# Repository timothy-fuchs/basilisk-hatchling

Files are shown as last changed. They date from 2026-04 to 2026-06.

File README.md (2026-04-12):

# basilisk-hatchling.github.io
Hatching a basilisk inside a Raspberry Pi Zero 2 W - based Macintosh

## License

Unless otherwise noted, the original content in this repository is licensed
under the Creative Commons Attribution-ShareAlike 4.0 International License
(CC BY-SA 4.0). See [LICENSE](./LICENSE) and the site [license page](./license.md).

That license applies only to material contained in this repository. It does not
extend to third-party materials or to any external repository, website, or
other internet resource linked from this project.

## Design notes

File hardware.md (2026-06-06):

---
layout: page
title: Hardware
permalink: /hardware/
---

# Things you absolutely need to obtain

Use this as a shopping checklist while gathering parts.

## 1. Maclock

Best sourced on AliExpress. Look for a listing with decent reviews. YMMV.

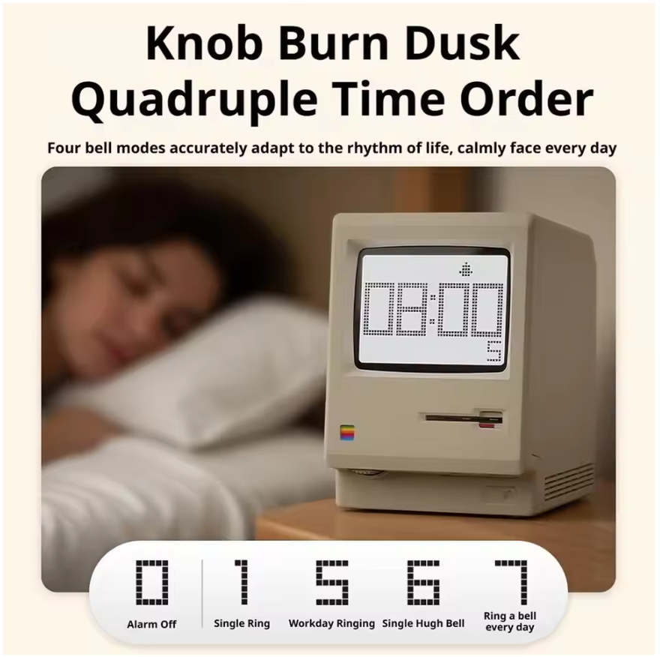
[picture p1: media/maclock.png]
Creative translation is an added bonus


## 2. Raspberry Pi Zero 2 W

Best sourced with the header already soldered on. If you can find a kit that includes a radiator, get it.

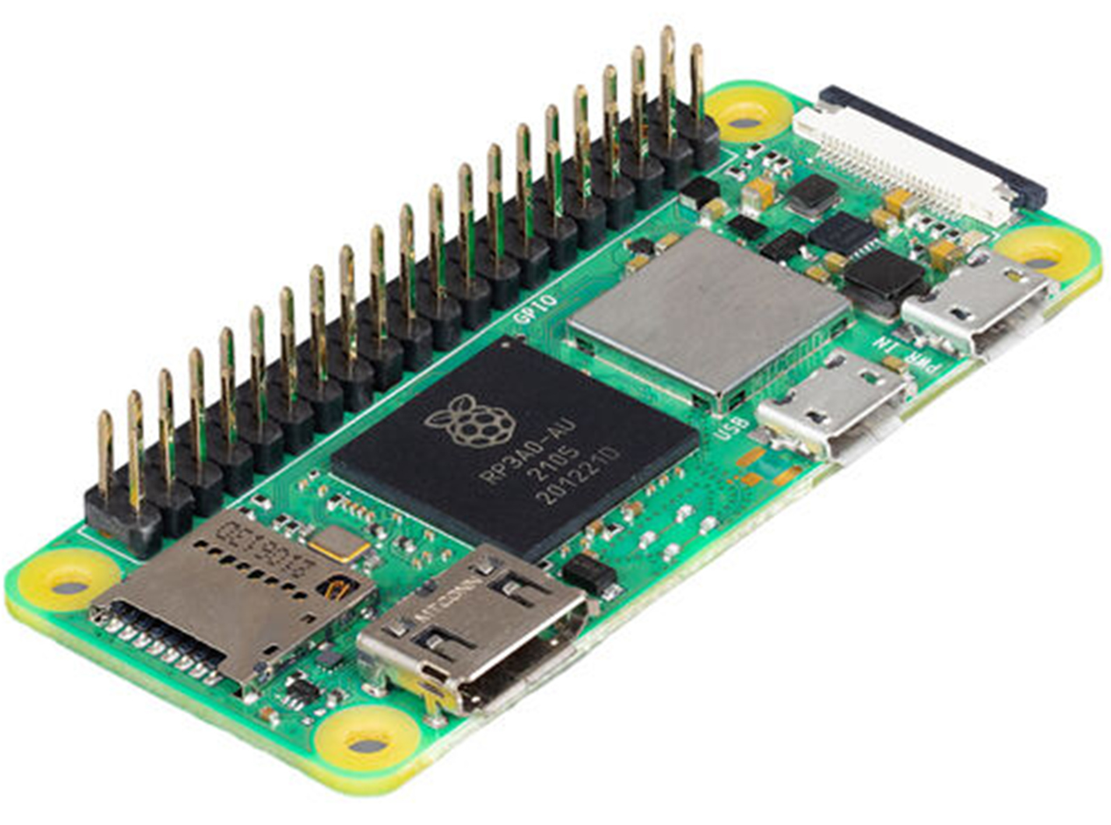
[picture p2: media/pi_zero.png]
Raspberry Pi


## 3. Waveshare 2.8" LCD display

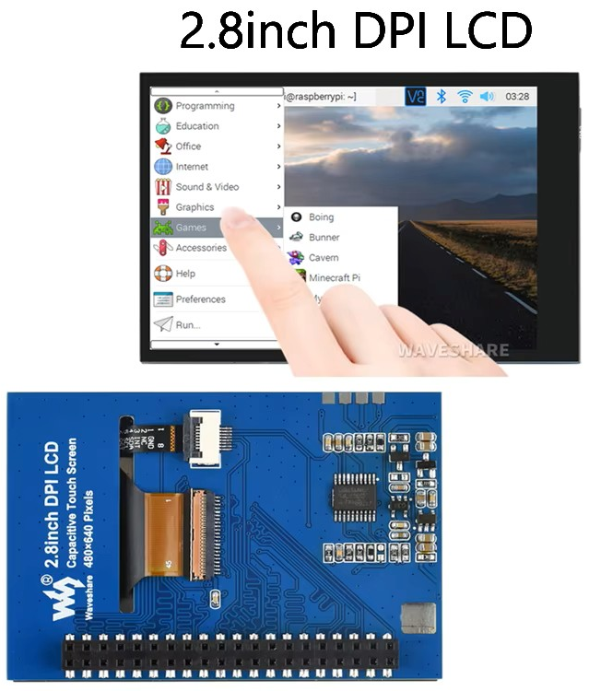
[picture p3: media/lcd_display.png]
LCD Display


## 4. Raspberry Pi 12mm header extender

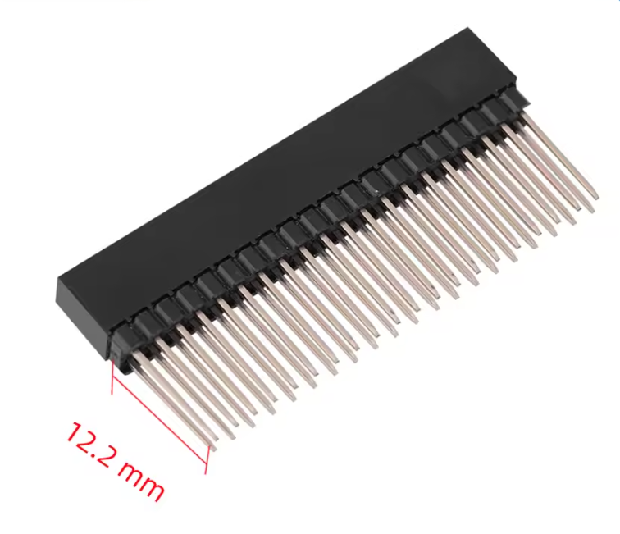
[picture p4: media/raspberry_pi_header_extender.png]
extender


## 5. Two angled microUSB-to-USB-C panel-mount adapters

Best sourced on AliExpress. Search term: `angled 90 microUSB to USB-C panel mount adapter`.

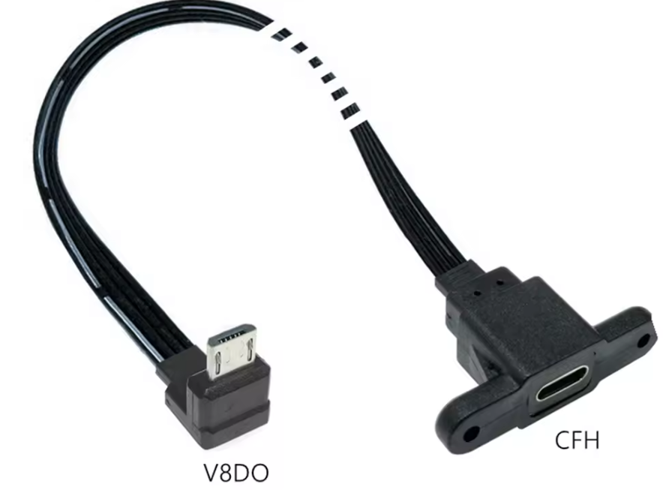
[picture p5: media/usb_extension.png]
Angled MicroUSB to USB-C panel mount


## 6. MicroSD extender

Best sourced on AliExpress. Search term: `microSD extension cable` or `sd card extension cable`.

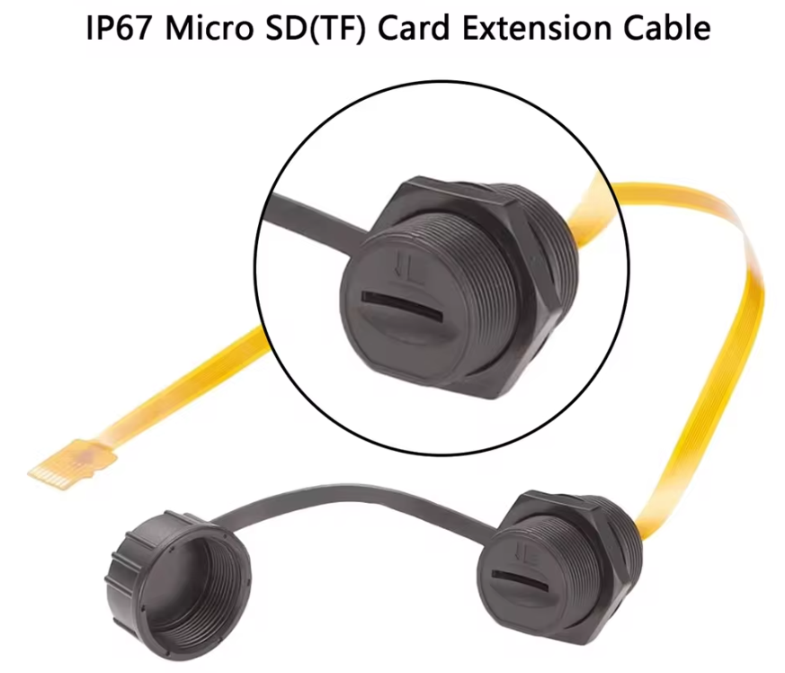
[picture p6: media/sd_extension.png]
MicroSD extender


## 7. USB-C to USB hub

Best sourced on AliExpress.

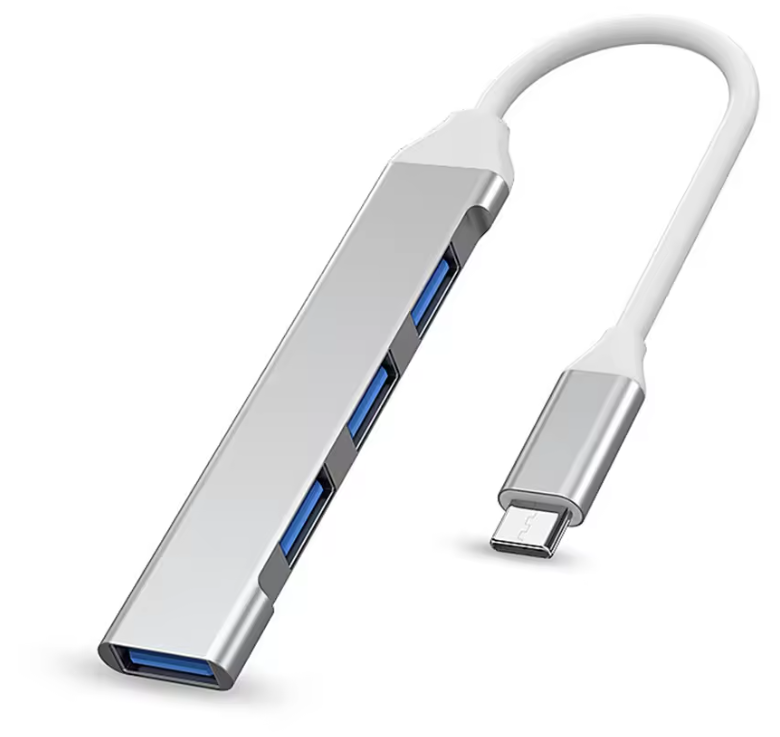
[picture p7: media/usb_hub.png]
USB


## 8. PWM sound HAT (optional)

This is supposed to work, but I have not tried it. Search for `dtoverlay=audremap,pins_18_19` if you want to test this option.

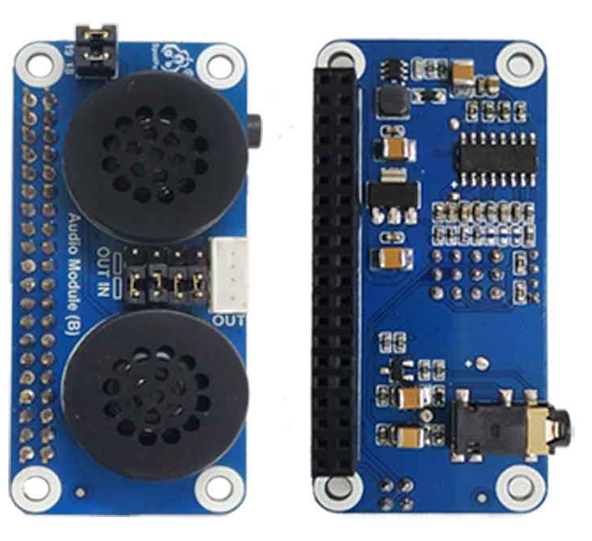
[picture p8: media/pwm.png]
PWM


## 9. USB audio dongle (optional)

Best sourced on AliExpress.

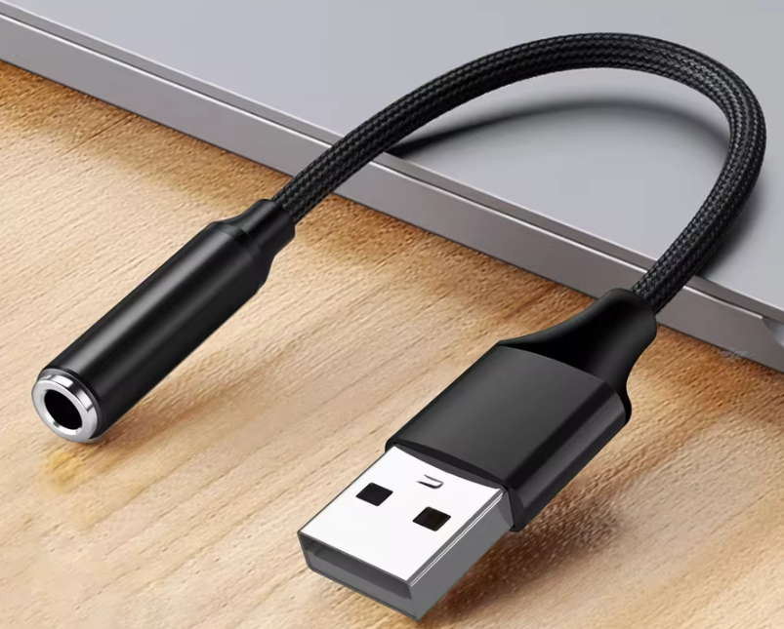
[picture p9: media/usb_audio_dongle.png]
USB Audio


## 10. Power supply

Best sourced on AliExpress. Search term: `USB-C power supply`.
I've been using this one, it works fine, but it is obviously not the only option. Raspberry Pi Zero 2 W has very modest power requirements.
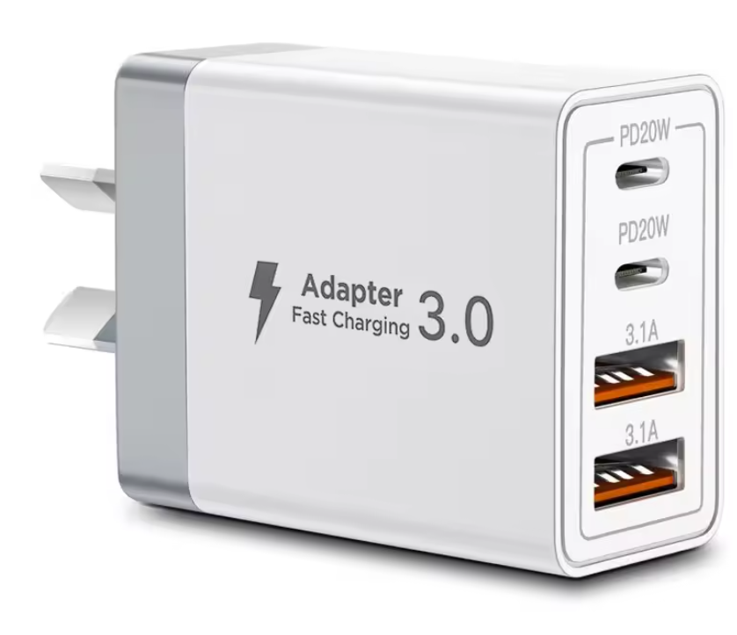
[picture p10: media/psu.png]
Power supply


# Things that you will need to 3D print

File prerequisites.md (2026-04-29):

---
layout: page
title: Prerequisites
permalink: /prerequisites/
---

# OS
Since we are going to use the SDL2 library, the X11 framework is a hindrance, so we will not install it at all.  
Use Raspberry Pi Imager to flash **Raspberry Pi OS Lite (32-bit)**.  
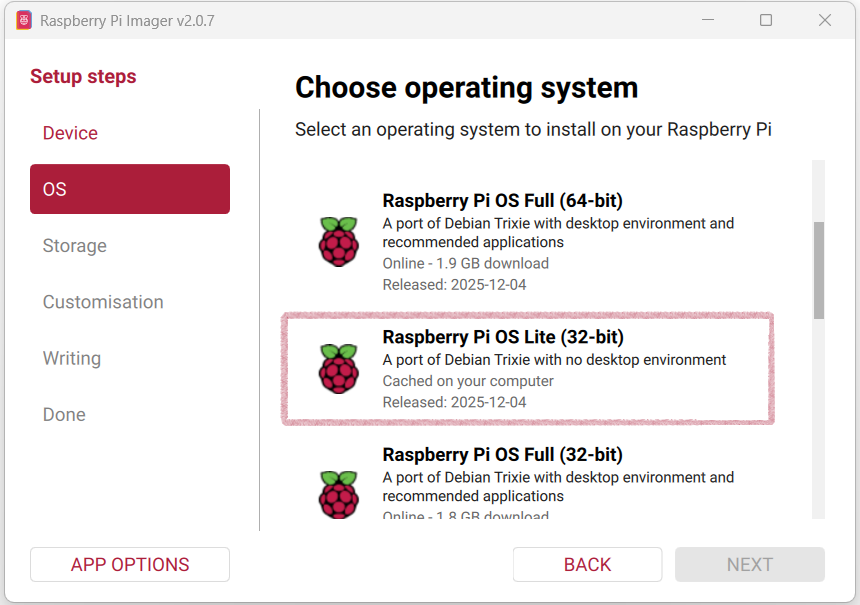
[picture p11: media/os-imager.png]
Raspberry Pi OS Lite - 32-bit


**Note:** Further instructions assume that we chose the default account name.

Flash the image onto the MicroSD card.

# Waveshare LCD drivers
*Note: Waveshare Wiki — [2.8inch DPI LCD](https://www.waveshare.com/wiki/2.8inch_DPI_LCD?spm=a2g0n.appdesc.0.0.130eA0ssA0ssp1&file=2.8inch_DPI_LCD)*  
Please read it before proceeding, since the process of deploying their driver may change.

Open the `config.txt` file in the root directory of the TF card, add the following lines at the end, and save:

```
dtoverlay=vc4-kms-v3d
dtoverlay=waveshare-28dpi-3b-4b   
dtoverlay=waveshare-28dpi-3b
dtoverlay=waveshare-28dpi-4b
dtoverlay=waveshare-touch-28dpi
dtoverlay=vc4-kms-dpi-2inch8
```

Download the DTBO file from  
https://files.waveshare.com/wiki/2.8inc-DPI-LCD/28DPI-DTBO.zip,  
unzip it, and copy the contents into `/boot/overlays`.

*At this stage, we should be ready to insert the TF card with the OS image into your Raspberry Pi and boot into the OS.*

```
sudo raspi-config
```
Enable SSH access.

# Console orientation
The first thing we will notice at boot time is that the console appears sideways.  
Build and install Basilisk, and its UI will appear sideways too (don’t ask me how I know).  
A `video` kernel command-line argument will not fix the problem for Basilisk, but we can at least correct the console at this stage.

Open the command-line arguments file for editing:

```sudo vi /boot/firmware/cmdline.txt```
and add the following in front of other arguments:
```video=DPI-1:480x640M@60,rotate=270 ```
Be sure to separate it from other arguments with a space and keep everything on the same line, or it won’t work.

# Build prerequisites
Before doing anything else, bring the OS up to date:

```
sudo apt update
sudo apt full-upgrade -y
sudo reboot
```

Since we will build the SDL2 library and Basilisk II emulator from source, we need to install the build tools and essential libraries:

```
sudo apt install -y \
    build-essential \
    git \
    autoconf \
    automake \
    libtool \
    pkg-config \
    libsdl2-dev \
    libasound2-dev \
    libslirp-dev \
    libgtk-3-dev \
    libgl1-mesa-dev \
    libgles2-mesa-dev
```

# Downloading, configuring, and building SDL2
*Note: Check the [download page](https://libsdl.org/release/) and get the latest SDL2 release. Do not download SDL3 (don’t ask me how I know).*

At the time of writing, **SDL2-2.32.10** was the latest release. Adjust accordingly.
```
mkdir projects
cd ~/projects
wget https://libsdl.org/release/SDL2-2.32.10.tar.gz
tar xf SDL2-2.32.10.tar.gz
cd SDL2-2.32.10
```

Configure SDL2 without X11, Wayland, PulseAudio, or OpenGL, and with KMSDRM
```
./configure \
    --disable-video-x11 \
    --disable-video-wayland \
    --disable-video-opengl \
    --disable-video-vulkan \
    --disable-pulseaudio \
    --disable-esd \
    --enable-video-kmsdrm \
    --enable-video-rpi \
    --enable-video-dummy
```

Build and install
```
make -j4
sudo make install
sudo ldconfig
```

This gives you a pure KMSDRM SDL2 build, ideal for headless Basilisk II.

# Downloading, configuring, and building Basilisk II
*Note: popular kanjitalk755 fork does not play nice with Waveshare LCD panels. This fork does.*
```
cd ~/projects
git clone https://github.com/timothy-fuchs/macemu.git
cd macemu/BasiliskII/src/Unix
```
Configure and build
`./autogen.sh`

Configure Basilisk II for:
* SDL2 video/audio
* No X11
* No GTK
* No JIT (safer on ARM)
* No VOSF

 ```
./configure --enable-sdl-video --enable-sdl-audio --disable-vosf --disable-jit --without-x --without-gtk --disable-nls --disable-esd --disable-mon
```
Build and deploy
```
make -j4
sudo make install
```

Before we go any further, let's install file hfs system utitlites that will make our life considerably more tolerable in the near future:
`sudo apt install hfsutils`

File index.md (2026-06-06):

---
layout: home
title: Home
---
This project is a miniature replica of the classic Macintosh, running Basilisk II on a Raspberry Pi Zero 2 W, and using a Waveshare 2.8" LCD display as the screen.

# Sinister but cute. Cute but sinister.
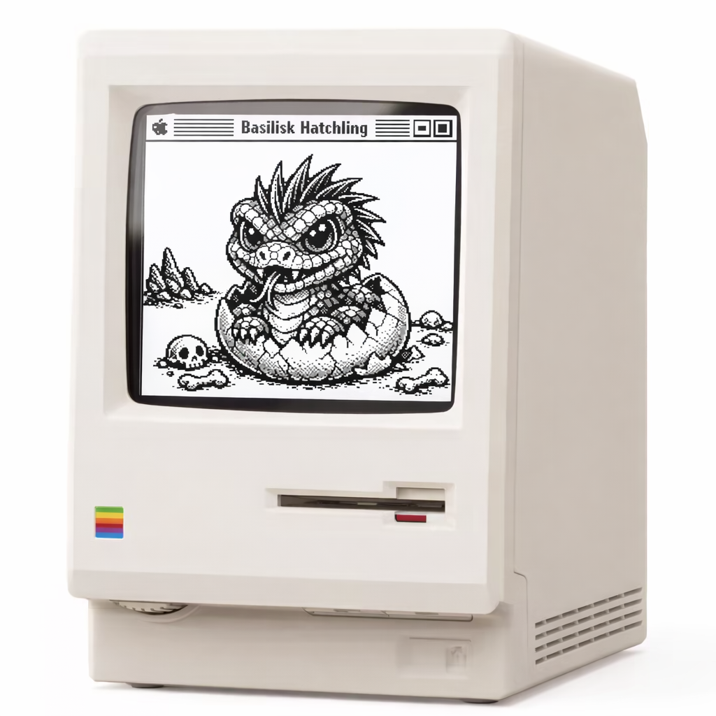
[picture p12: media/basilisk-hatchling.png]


The inspiration for this project came from this video by @ThisDoesNotCompute:

<div style="position: relative; padding-bottom: 56.25%; height: 0; overflow: hidden;">
    <iframe
        src="https://www.youtube.com/embed/dRr5iVjMfqs"
        style="position: absolute; top: 0; left: 0; width: 100%; height: 100%;"
        frameborder="0"
        allowfullscreen>
    </iframe>
</div>

He has done an amazing job finding the right parts and putting everything together, however, I felt that his choice of the OS and emulator was not optimal, and I decided to do it my own way, documennting my journey along the way.

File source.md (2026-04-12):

# Basilisk Hatchling
[media/basilisk__hatchling.png]

## Parts
* Raspberry Pi Zero W 2
* Waveshare 2.8" LCD monitor
* 
Lorem ipsum

## Installation process
* Correct at the time of writing *
* OS - raspbian Trixie Lite (headless)
** install with the default settings.
** Configure WiFi.
** Enable ssh.

** Configure the LCD
*Note: Waveshare Wiki is here: https://www.waveshare.com/wiki/2.8inch_DPI_LCD?spm=a2g0n.appdesc.0.0.130eA0ssA0ssp1&file=2.8inch_DPI_LCD*
*** Open the config.txt file in the root directory of the TF card, add the following code at the end of the config.txt and save:
```
dtoverlay=vc4-kms-v3d
dtoverlay=waveshare-28dpi-3b-4b   
dtoverlay=waveshare-28dpi-3b
dtoverlay=waveshare-28dpi-4b
dtoverlay=waveshare-touch-28dpi
dtoverlay=vc4-kms-dpi-2inch8
```
Download the DTBO file https://files.waveshare.com/wiki/2.8inc-DPI-LCD/28DPI-DTBO.zip , unzip and copy into /boot/overlays

** Ssh into the hatchling.

*** Enable VNC.
*** To correct screen orientation, add the following to the beginning of `/boot/firmware/cmdline.txt`, separate by space.
`video=DPI-1:480x640M@60,rotate=270`

*** Update the system
```
sudo apt update
sudo apt full-upgrade -y
sudo reboot
```

*** Install the prerequisites
```
sudo apt install -y \
    build-essential \
    git \
    autoconf \
    automake \
    libtool \
    pkg-config \
    libsdl2-dev \
    libasound2-dev \
    libslirp-dev \
    libgtk-3-dev \
    libgl1-mesa-dev \
    libgles2-mesa-dev
```

*** Download, configure, and build SDL2 (Headless / KMSDRM Only)
*Note: check the download page, download the latest release of SDL2 available. Do not download SDL3*
```
cd ~
wget https://libsdl.org/release/SDL2-2.32.10.tar.gz
tar xf SDL2-2.32.10.tar.gz
cd SDL2-2.32.10
```

** Configure SDL2 without X11, Wayland, PulseAudio, or OpenGL, and with KMSDRM
```
./configure \
    --disable-video-x11 \
    --disable-video-wayland \
    --disable-video-opengl \
    --disable-video-vulkan \
    --disable-pulseaudio \
    --disable-esd \
    --enable-video-kmsdrm \
    --enable-video-rpi \
    --enable-video-dummy
```
*** Build and install
```
make -j4
sudo make install
sudo ldconfig
```
This gives you a pure KMSDRM SDL2, ideal for headless Basilisk II.

** Clone and build Basilisk II
*Note: the credit for porting Basilisk II to SDL2 goes to kanjitalk755, but his implementation does not play nice with waveshare LCD panels. My fork does.*
```
cd ~
git clone https://github.com/timothy-fuchs/macemu.git
cd macemu/BasiliskII/src/Unix
```

*** Configure and build 
`./autogen.sh`

*** Configure Basilisk II for:

**** SDL2 video/audio
**** No X11
**** No GTK
**** No JIT (safer on ARM)
**** No VOSF
 
 ```
./configure     --enable-sdl-video     --enable-sdl-audio     --disable-vosf     --disable-jit     --without-x     --without-gtk     --disable-nls     --disable-esd     --disable-mon
```

Install the hfs utilities
`sudo apt install hfsutils`

Create the main drive image
dd ...
Create the transfer drive image

Create the basilisk configuration.
Mount the boot floppy disk
Boot - at this stage you should get

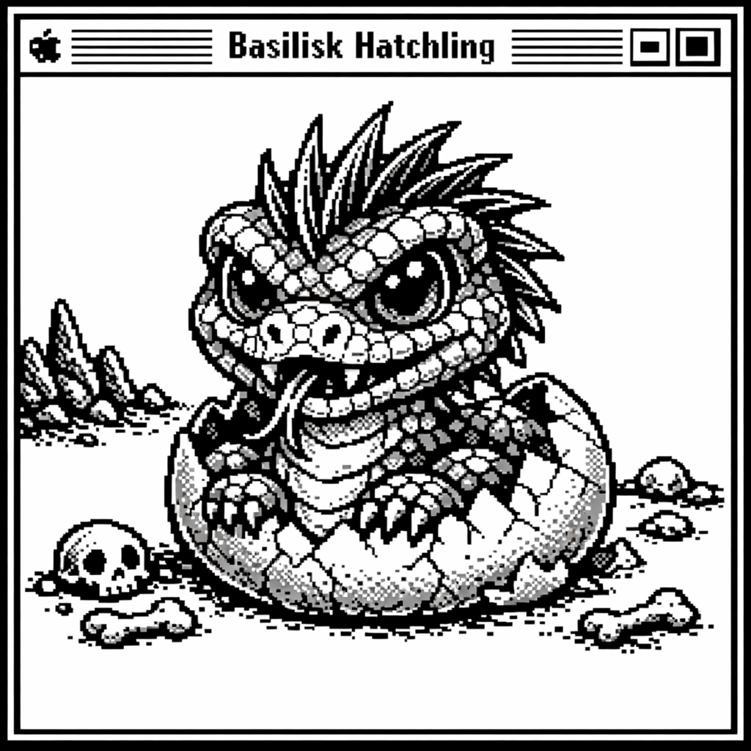
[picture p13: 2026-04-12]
media/basilisk-hatchling-window.png

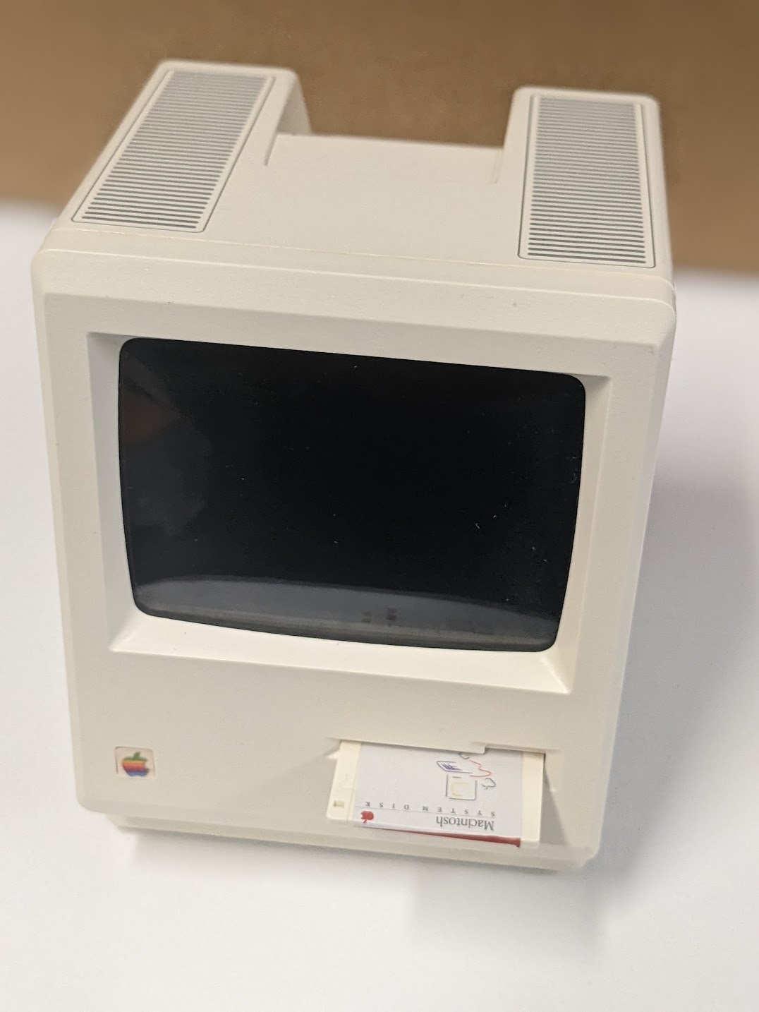
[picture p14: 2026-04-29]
media/mac_front.jpg

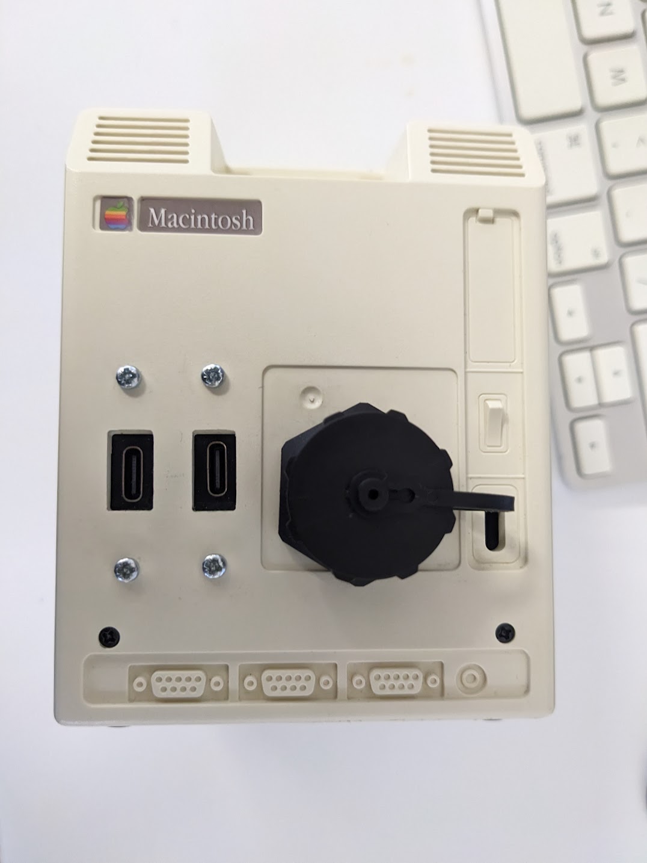
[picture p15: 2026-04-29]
media/mac_back.jpg

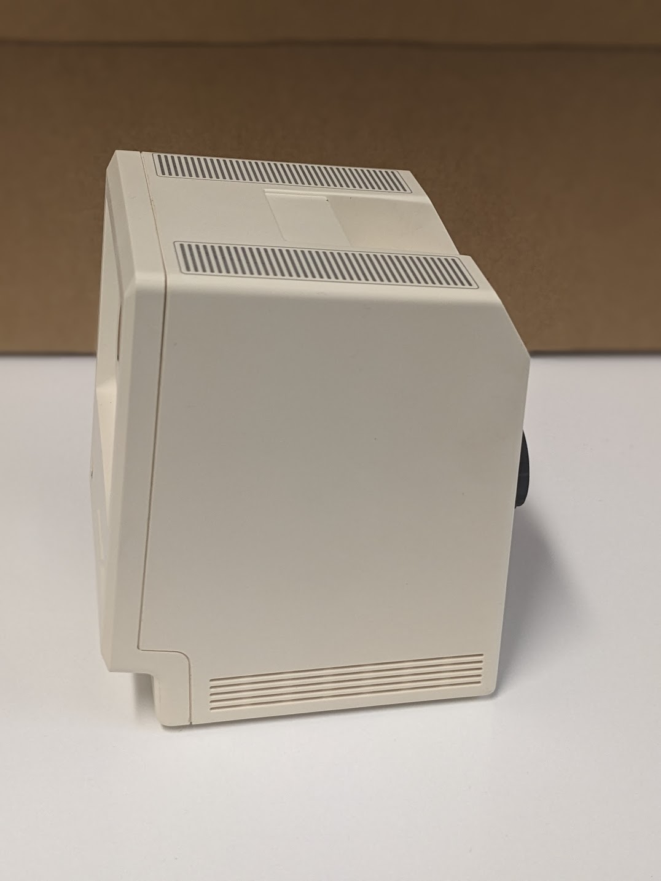
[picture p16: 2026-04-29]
media/mac_side.jpg

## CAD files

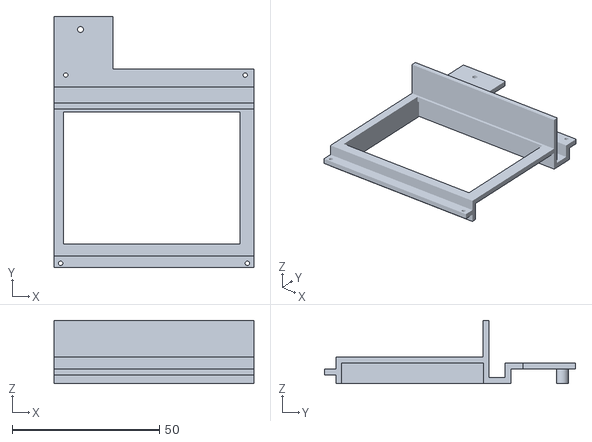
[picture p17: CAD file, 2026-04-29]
media/wondermac-screen-bracket-full-image-remix.stl
68.0 x 85.5 x 21.5

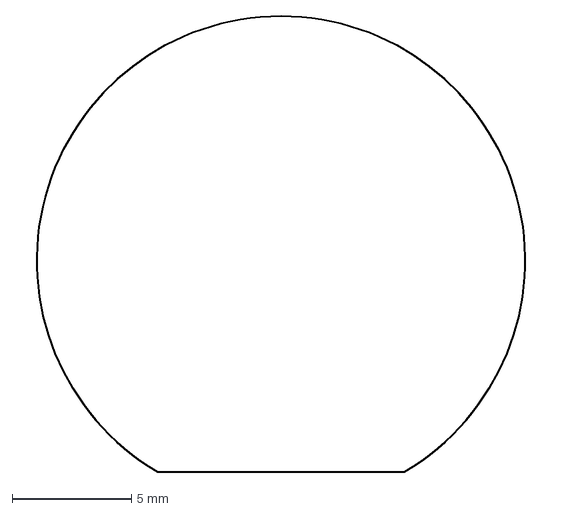
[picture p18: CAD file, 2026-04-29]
media/microsd_reader_aperture.dxf
22.2 x 19.1 mm

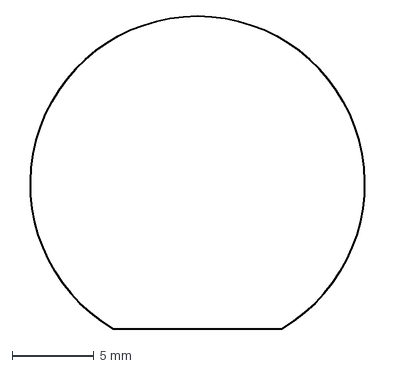
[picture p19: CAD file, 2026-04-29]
media/cf_card_slot.dxf
22.2 x 19.1 mm

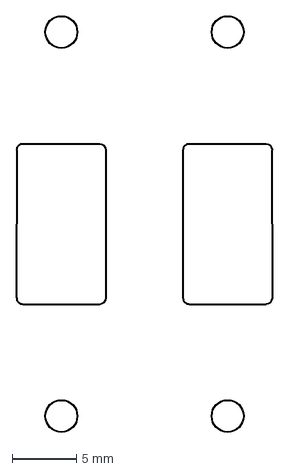
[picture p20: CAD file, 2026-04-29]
media/usb_cutouts.dxf
20.0 x 32.5 mm

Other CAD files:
media/wondermac-screen-bracket-full-image.stl

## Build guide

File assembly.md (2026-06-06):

---
layout: page
title: Assembly
permalink: /assembly/
---
Disassembly of the Maclock is the hardest part of the entire project. Below is a step-by-step guide to disassembling the Maclock and preparing it for the installation of the Raspberry Pi and LCD display. I can only add that the process is quite tedious and that you are guaranteed to break at least one of the plastic clips. Make sure you break the clips at the bottom, because it is invisible and does not affect the aesthetics of the final product. Use a plastic prying tool to avoid damaging the case. Take your time and be patient.

<div style="position: relative; padding-bottom: 56.25%; height: 0; overflow: hidden;">
    <iframe
        src="https://www.youtube.com/embed/WEVMEvV_sOM"
        style="position: absolute; top: 0; left: 0; width: 100%; height: 100%;"
        frameborder="0"
        allowfullscreen>
    </iframe>
</div>

Once you have disassembled the Maclock, you will need to prepare the case for the installation of the Raspberry Pi and LCD display. The original instructable, linked below for your reference, reuses the original charging port by rewiring the charging socket board. I found this to be tedious. The wiring is fragile, and once soldered, the two parts of the maclock case cannot be separated without breaking the wires. Raspberry Pi Zero 2 W has a micro USB port for power, and there is no reason to not make use of it and try to use the probe pads on the Raspberry Pi for power instead. I left the original charging port in place, unconnected and cut two holes in the case back for two USB ports, one for power and one for the USB hub. I chose to use Micro USB to USB-C panel mount adapters for the ports, because they are sturdy and robust unlike the increasingly rare and fragile Micro USB ports.

Additionally, I cut a large hole in the back of the case for the CF card slot, so that I could easily reprogram the Raspberry Pi without having to open the case.

*Power switch*:
Angled MicroUSB to USB-C panel mount
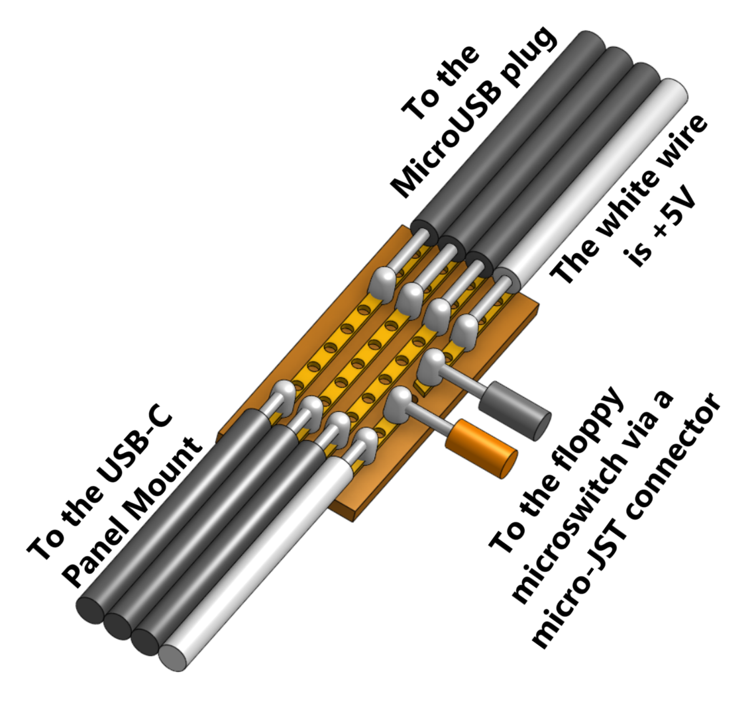
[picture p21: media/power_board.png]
Bypass
    
I  cut one of the Micro USB to USB-C cables in half and inserted a DIY bypass with a switch, using a micro-JST pigtail and a piece of stripboard to allow to turn the power on and off without having to unplug the cable. It allowed me to use the mock floppy drive as a power switch, which is a nice touch, if I do say so myself.

For your build, you can follow the instructable below, with the appropriate adjustments. 
*Nota Bene!:* 

The instructable calls for trimming the borders with a pair of side cutters. I found this to be entirely unnecessary, and I did not do it. The 3D printed LCD display frame fits perfectly in the original opening without any modifications, and the borders are not visible when the case is closed.

[Instructable](https://www.instructables.com/Wireless-Mini-Mac-From-a-Maclock/)

The video below takes this project one siginificant step further than I did by adding a custom PCB for the Raspberry Pi and reusing the the original brigtness control knob and two pushbuttons. It also adds an internal speaker for even greater authenticity. It is an amazing project, and if you feel adventurous, you can try to follow his instructions to add these features to your build as well.

<div style="position: relative; padding-bottom: 56.25%; height: 0; overflow: hidden;">
    <iframe
        src="https://www.youtube.com/embed/zAbAf5-H5Yo"
        style="position: absolute; top: 0; left: 0; width: 100%; height: 100%;"
        frameborder="0"
        allowfullscreen>
    </iframe>
</div>

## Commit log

2026-04-12 Switch to Jekyll light theme; add stub markdown pages
    Agent-Logs-Url: https://github.com/timothy-fuchs/basilisk-hatchling.github.io/sessions/ab3627d5-db72-448a-8537-29af0292d08c
2026-04-29 Added some media
    [cf_card_slot.dxf, microsd_reader_aperture.dxf, usb_cutouts.dxf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]
